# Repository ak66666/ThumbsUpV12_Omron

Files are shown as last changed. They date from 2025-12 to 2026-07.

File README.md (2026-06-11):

# ThumbsUp! v12 RP2040-based ProMicro 3x12 chord keyboard for Omron and mouse switches.
                           
Steno/chord keyboard (number key instead of a bar)
2-key Thumb Cluster
Cirque ProGlide trackpad/touchpad

Omron mouse switches or 6x6 two-pin switches.

* RP2040 ProMicro x2
* TRS (3-wire) audio cable to connect the halves.
* USB-C connectors.

Silicone O-rings are used for the key paddles suspension: CS2.4mm, OD 11mm (12mm works too).
Cross section 2-2.5 mm works well.
OD less than 11mm result in much heavier keys. 
OD more than 12mm is a bit too loose.

# Rev.5

Re-worked the cross-board connections: 
Replaced the mix of pin headers/sockets and stand-offs with individual stand-off for each key, plus one in a corner.
This way the boards should stay flat, no twisting due to minor height mismatch and the connectors pulled upwards unevenly.
Hopefully that will equalize the key reactions, uniform the feel.

Split the top board in two parts - to move the thumb keys higher and a bit closer to the index finger column. 
If it was left as a single detail - it would be C-shaped board with a thin profile, could be easily broken, and, probably, harder to manufacture and deliver.

Moved the MCU, connectors to make room for the stand-offs, re-laid the tracks where affected.

# Rev.4

Moved the keys as in rev.1, as the rev.3 inherited the spacing from rev.2 and was a bit uncomfortable.

# Rev.3

Approx. 15g activation with Omron switches, reduced from the previous revisions.
Cirque ProGlide trackpad support - on both or one of the sides.
Handiness pin added.

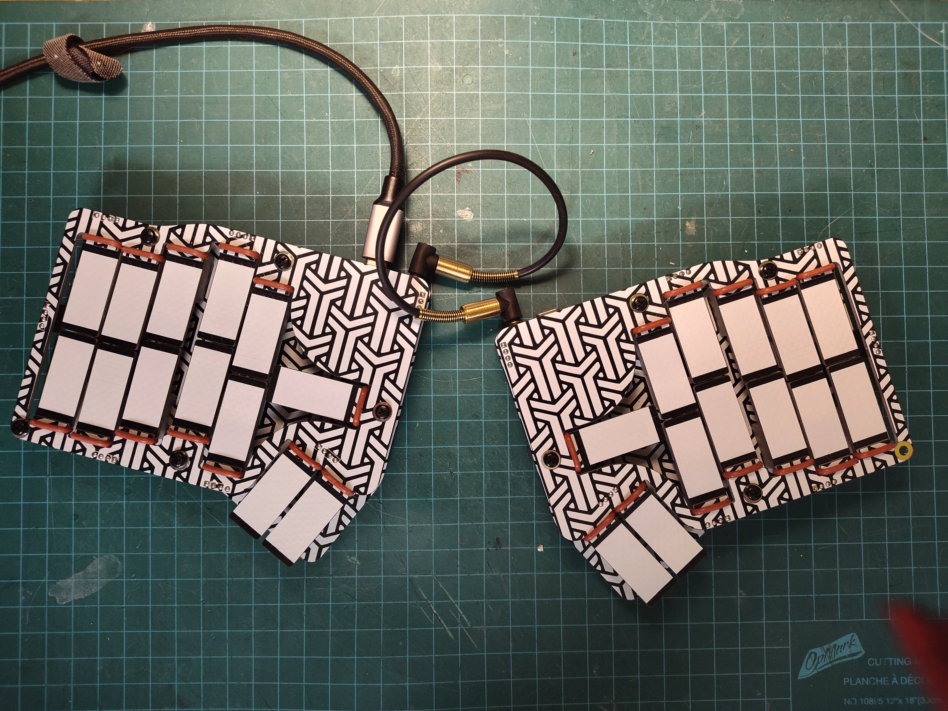
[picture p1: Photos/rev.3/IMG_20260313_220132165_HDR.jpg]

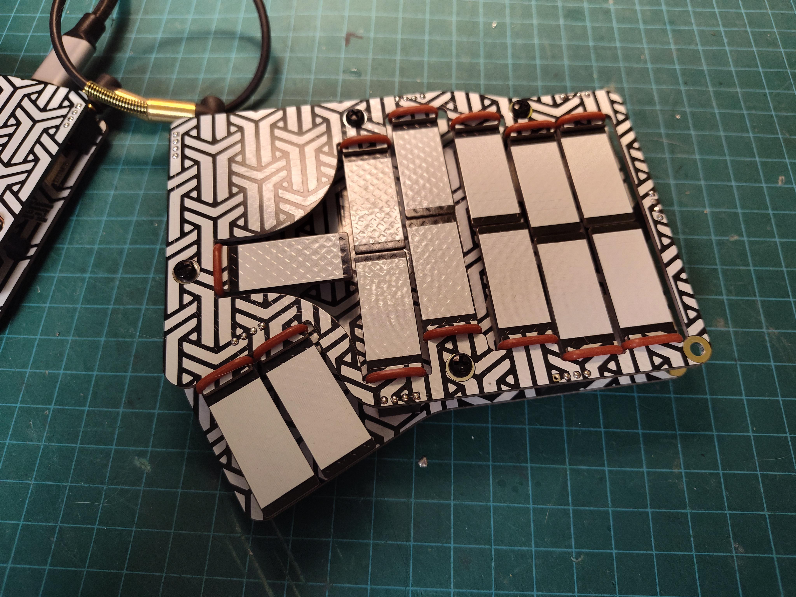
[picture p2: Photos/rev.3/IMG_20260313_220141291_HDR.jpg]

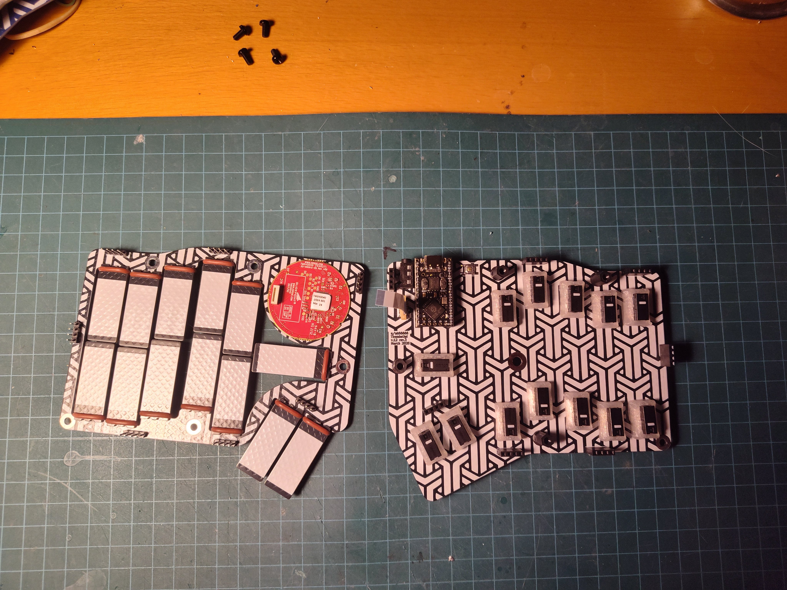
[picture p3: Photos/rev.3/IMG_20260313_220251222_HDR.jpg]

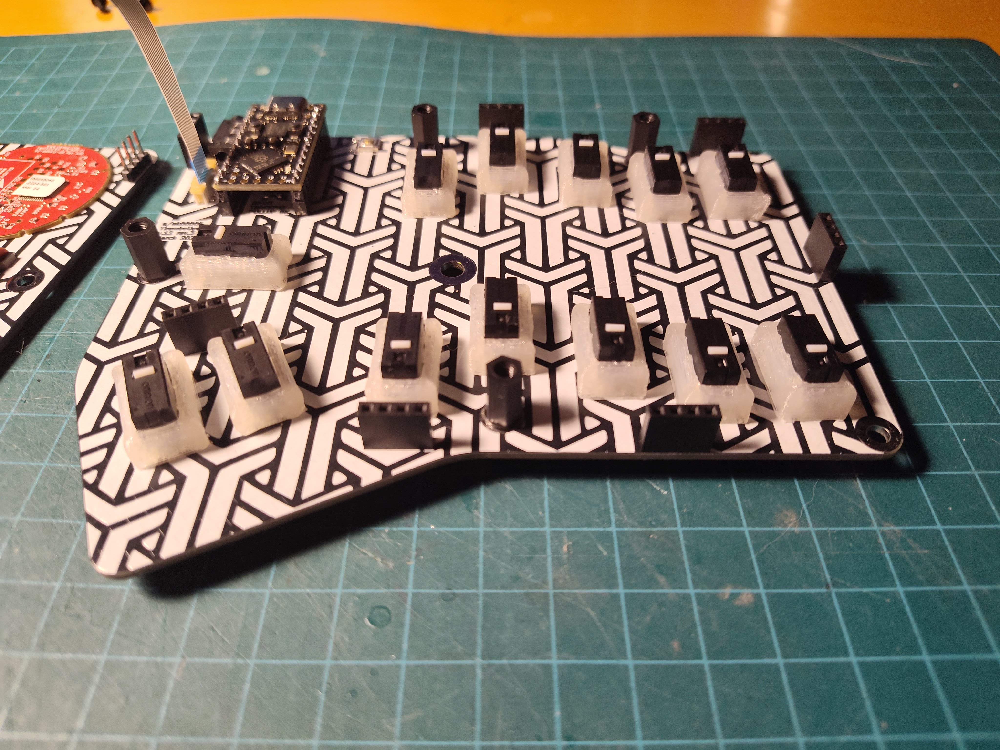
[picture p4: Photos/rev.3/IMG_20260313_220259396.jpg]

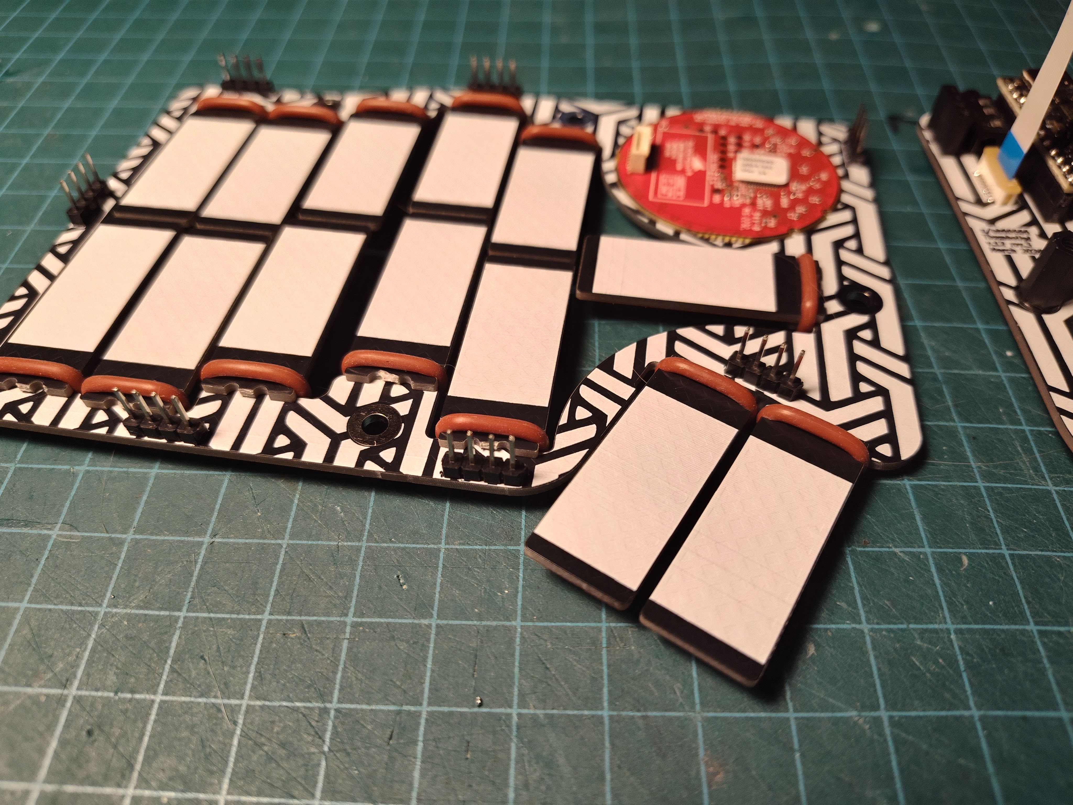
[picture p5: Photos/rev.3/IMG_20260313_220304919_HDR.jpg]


# Rev.2

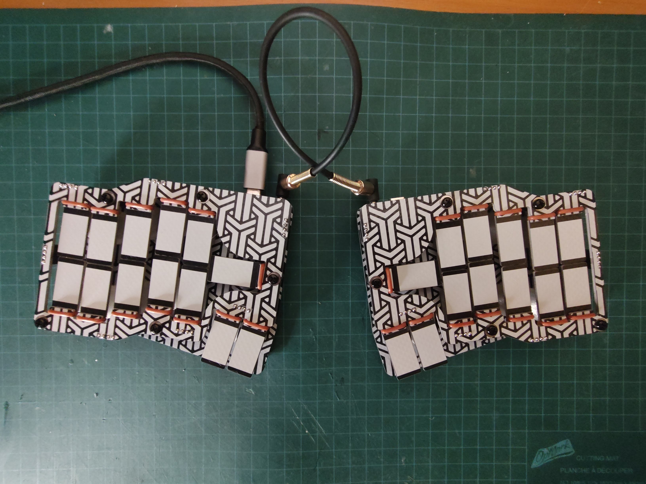
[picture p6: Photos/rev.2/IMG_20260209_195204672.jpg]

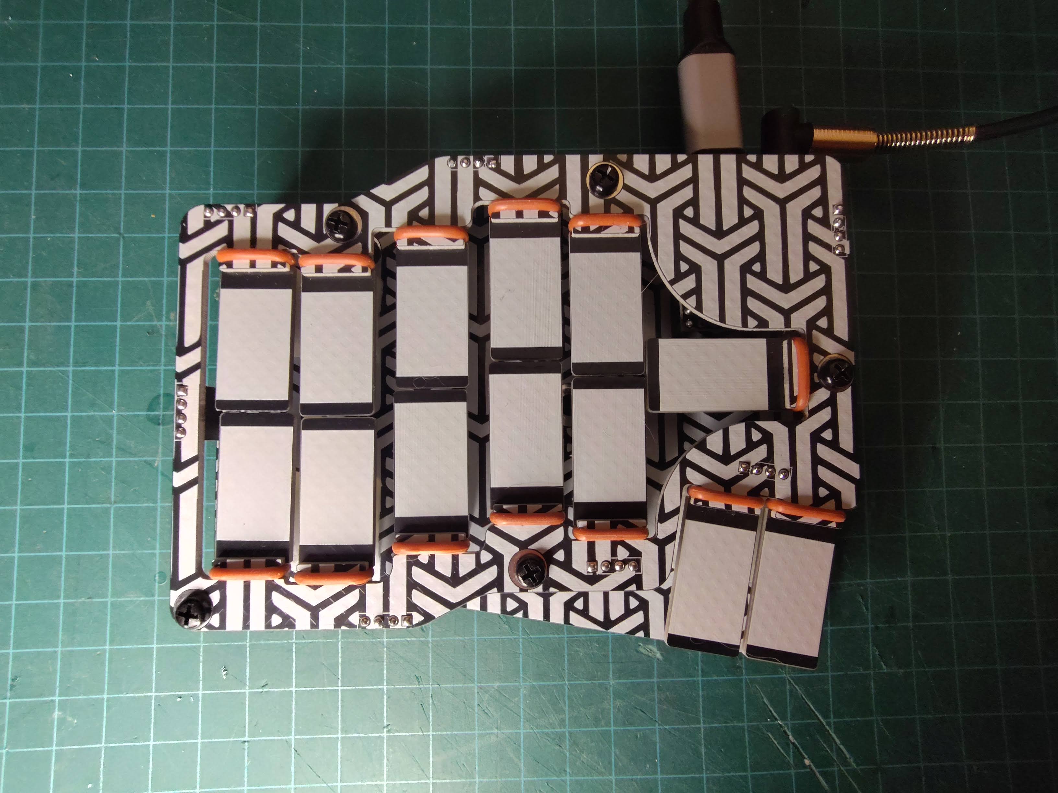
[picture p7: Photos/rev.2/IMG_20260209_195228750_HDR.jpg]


# Rev.1

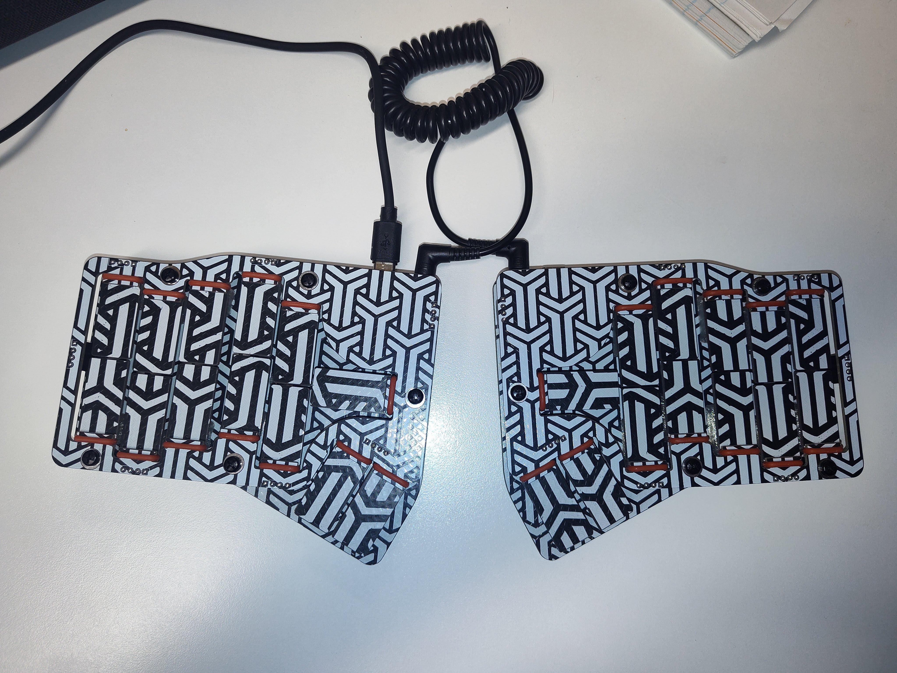
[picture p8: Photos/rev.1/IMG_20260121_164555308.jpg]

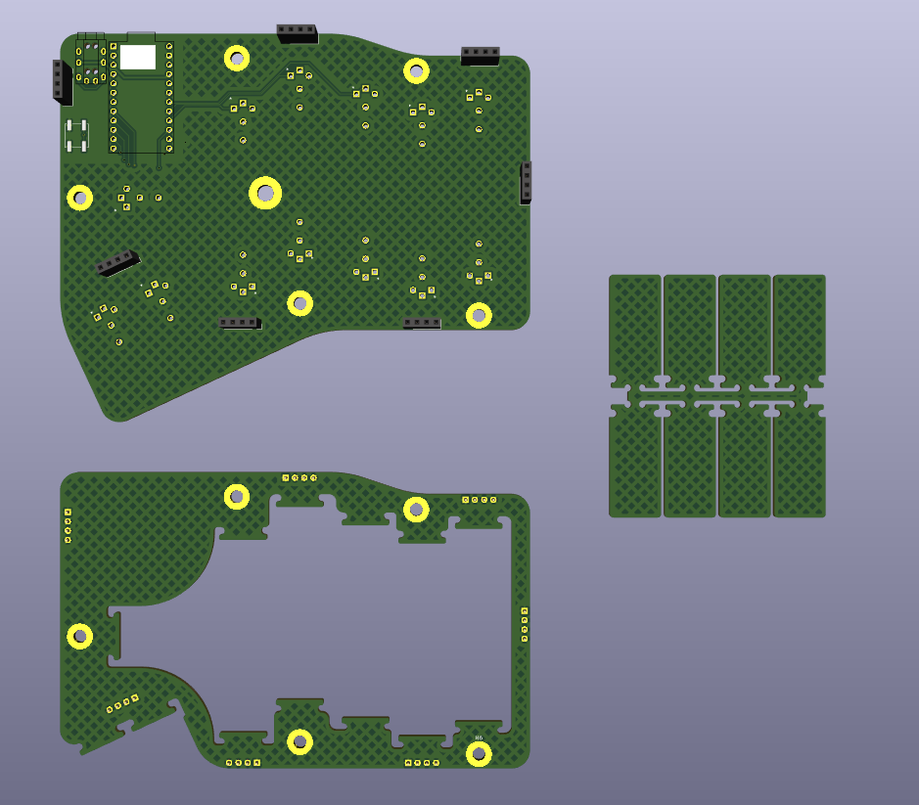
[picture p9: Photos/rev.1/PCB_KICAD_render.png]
PCB Render

 
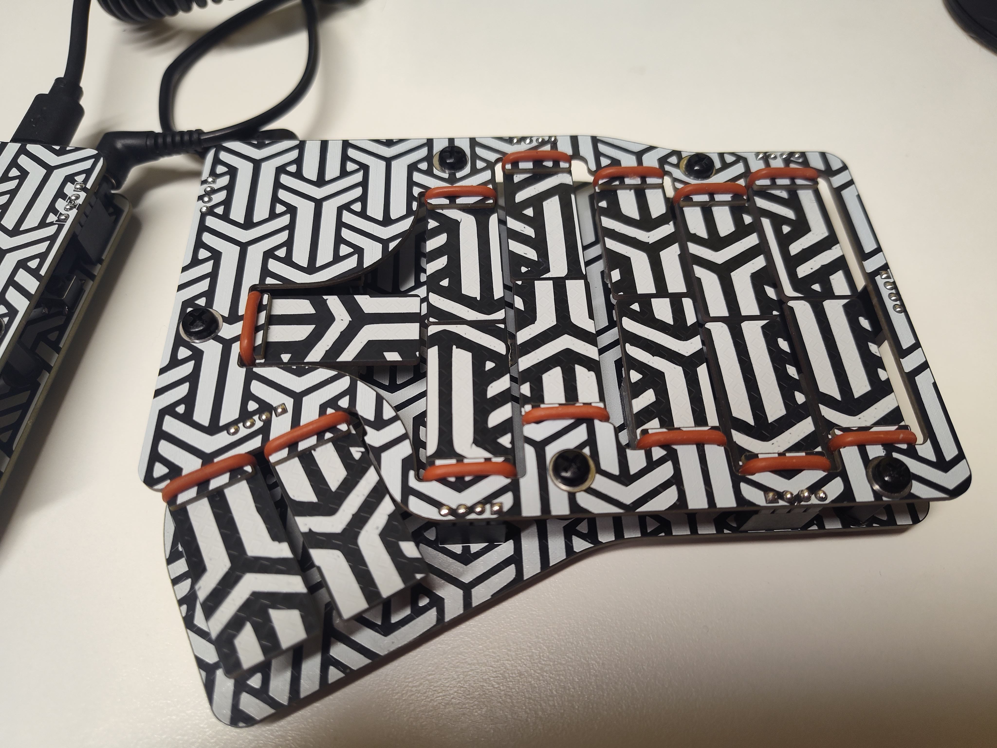
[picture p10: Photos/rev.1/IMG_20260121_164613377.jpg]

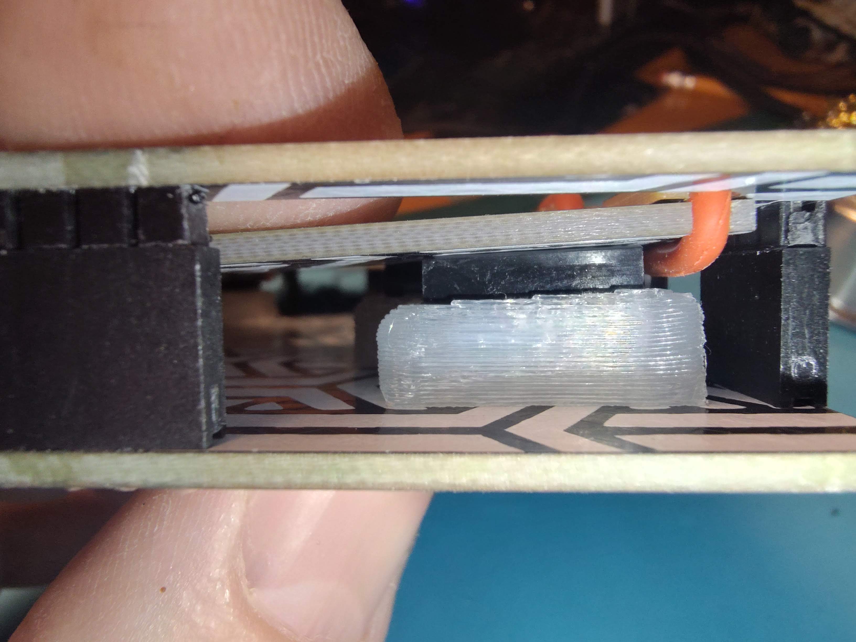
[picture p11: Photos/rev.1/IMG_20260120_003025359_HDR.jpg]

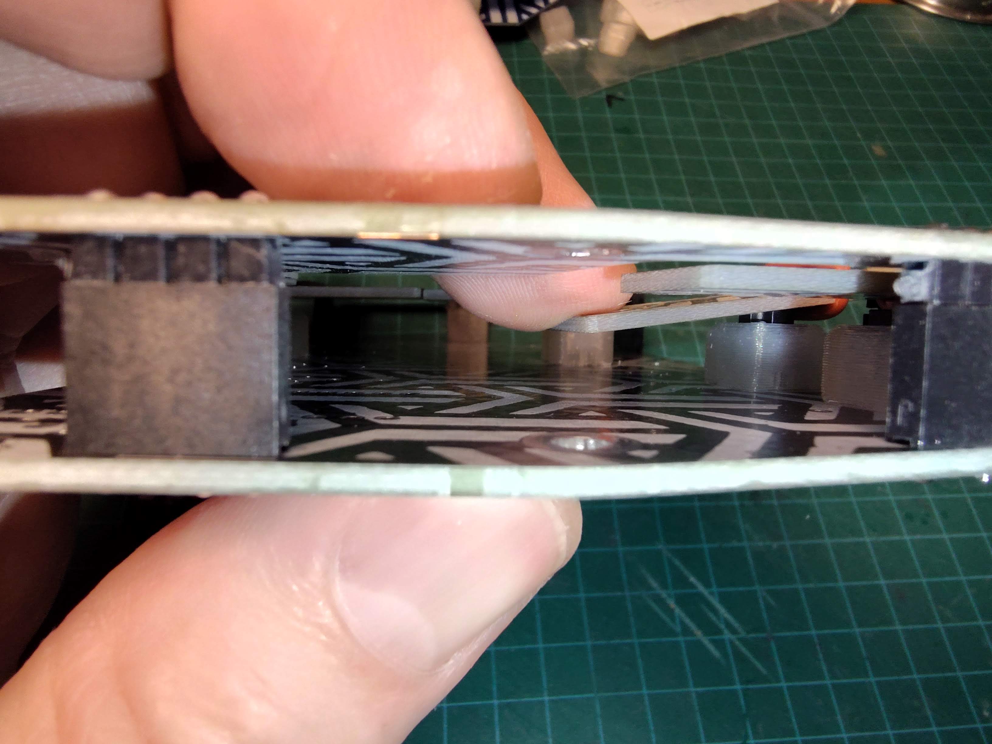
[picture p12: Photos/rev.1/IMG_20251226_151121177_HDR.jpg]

Main view

Other pictures and videos in Photos folder.

# Firmware

TX-Bolt interface as the only connectivity option for now:
https://github.com/ak66666/qmk_firmware/tree/thumbsup_20240523/keyboards/thumbsup/rev12_rp2040_split_steno

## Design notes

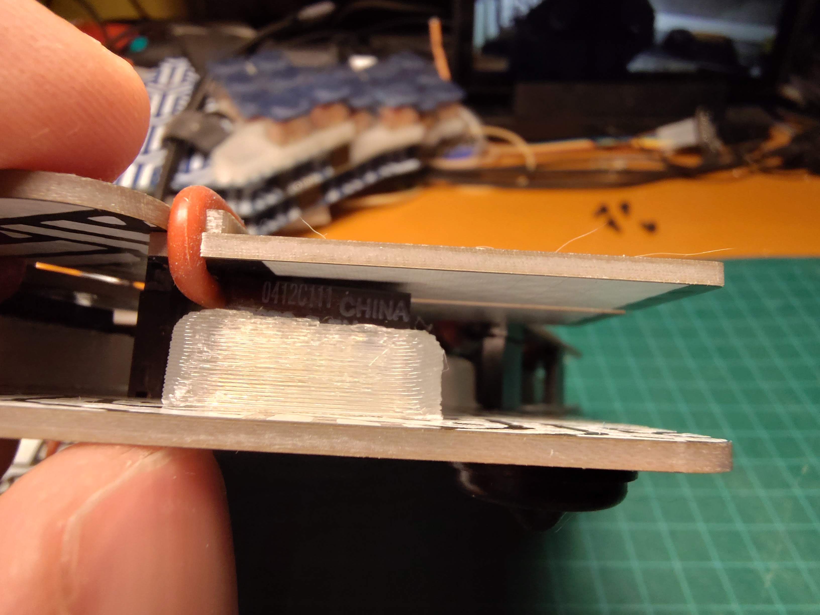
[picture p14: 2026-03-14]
Photos/rev.3/IMG_20260313_220356602_HDR.jpg

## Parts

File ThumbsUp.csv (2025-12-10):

Id | Designator | Package | Quantity | Designation | Supplier and ref
1 | RUN,BOOTSEL | TL1016AAF220QG | 2 | TL1016AAF220QG
2 | IC1 | QFN40P700X700X90-57N-D | 1 | RP2040
3 | D25,D44,D43,D42,D41,D40,D39,D38,D37,D36,D35,D34,D33,D32,D31,D30,D29,D28,D27,D26,D24,D23,D22,D21,D20,D19,D18,D17,D16,D15,D14,D13,D12,D11,D10,D9,D8,D7,D6,D5,D4,D3,D2,D1 | D_SOD-123 | 44 | D_Small
4 | Y1 | HC%2f49US-(AT49)_1 | 1 | ABLS-12.000MHZ-B4-T
5 | R3 | R_0805_2012Metric | 1 | 10k
6 | IC2 | SOIC127P790X216-8N | 1 | W25Q128JVSIM
7 | C9,C11 | C_0805_2012Metric | 2 | 10uF
8 | C7,C6,C2,C1,C17,C16,C15,C14,C13,C10 | C_0805_2012Metric | 10 | 0.1uF
9 | C5,C4 | C_0805_2012Metric | 2 | 27pF
10 | C3,C12 | C_0805_2012Metric | 2 | 1uF
11 | U1 | SOT-223-3_TabPin2 | 1 | NCP1117-3.3_SOT223
12 | R7 | R_0805_2012Metric | 1 | DNF
13 | R6 | R_0805_2012Metric | 1 | 1k
14 | R5,R4 | R_0805_2012Metric | 2 | 4.7k
15 | R2,R1 | R_0805_2012Metric | 2 | 27.4
16 | F1 | Fuse_1206_3216Metric | 1 | Polyfuse
17 | USB1 | Molex-0548190589 | 1 | Molex-0548190589
18 | J27,J24,J25,J26,J6,J4 | PinHeader_1x04_P2.54mm_Vertical | 6 | Conn_01x04_Male
19 | J18,J10,J14 | PinHeader_1x04_P2.54mm_Vertical | 3 | Raiser_Male
20 | MX38 | Kailh_socket_PG1350_optional | 1 | SwMENU
21 | MX27 | Kailh_socket_PG1350_optional | 1 | SwU
22 | MX28 | Kailh_socket_PG1350_optional | 1 | SwJ
23 | MX29 | Kailh_socket_PG1350_optional | 1 | SwM
24 | MX34 | Kailh_socket_PG1350_optional | 1 | SwRALT
25 | J20,J21,J22,J23 | PinSocket_1x04_P2.54mm_Vertical | 4 | Conn_01x04_Female
26 | MX15 | Kailh_socket_PG1350_optional | 1 | SwR
27 | MX24 | Kailh_socket_PG1350_optional | 1 | SwH
28 | MX10 | Kailh_socket_PG1350_optional | 1 | SwLWIN
29 | MX14 | Kailh_socket_PG1350_optional | 1 | SwLALT
30 | MX17 | Kailh_socket_PG1350_optional | 1 | SwV
31 | MX25 | Kailh_socket_PG1350_optional | 1 | SwN
32 | MX19 | Kailh_socket_PG1350_optional | 1 | SwT
33 | MX21 | Kailh_socket_PG1350_optional | 1 | SwB
34 | MX20 | Kailh_socket_PG1350_optional | 1 | SwG
35 | MX23 | Kailh_socket_PG1350_optional | 1 | SwY
36 | MX16 | Kailh_socket_PG1350_optional | 1 | SwF
37 | J15,J11 | PinSocket_1x04_P2.54mm_Vertical | 2 | Raiser_Female

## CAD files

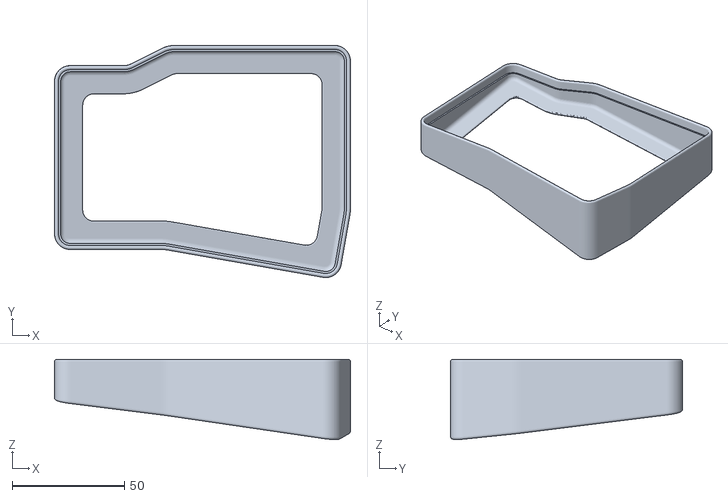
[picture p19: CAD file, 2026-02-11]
3D Printed/Base.stl
132.0 x 103.5 x 35.7

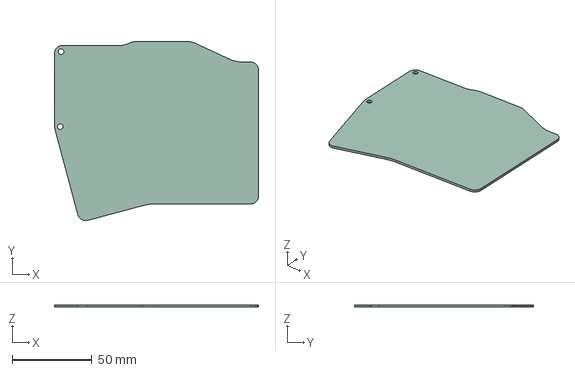
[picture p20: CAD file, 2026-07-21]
3D Printed/Rev.5/Bottom Plate rev.5.step
128.0 x 112.6 x 1.51 mm

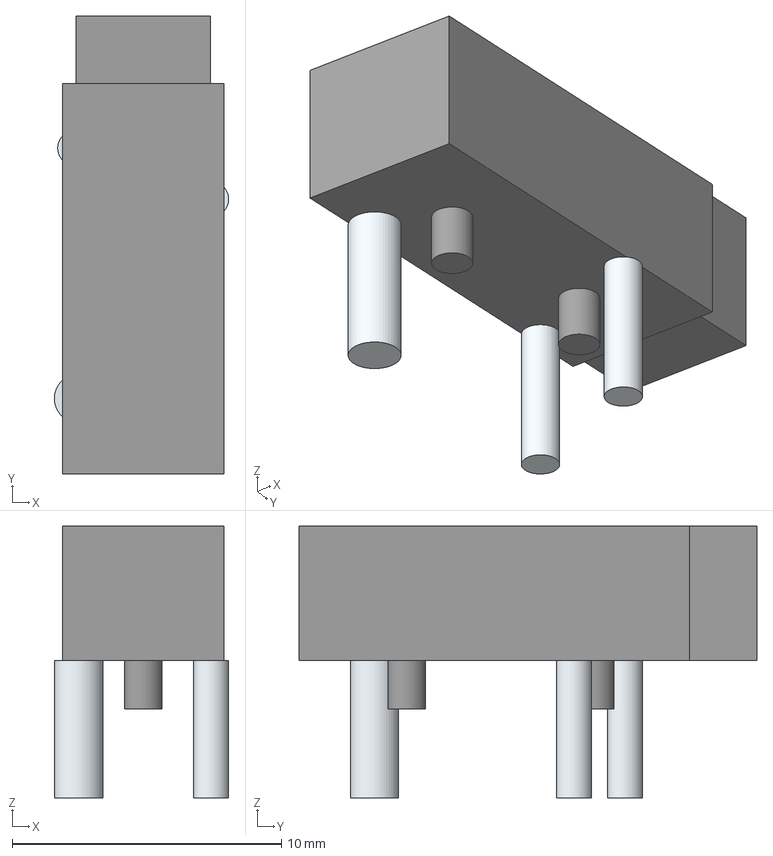
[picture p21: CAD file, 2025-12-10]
STX-3501-3N/3D/STX-3501-3N.stp
6.47 x 17.0 x 10.1 mm
Lugs
Leads

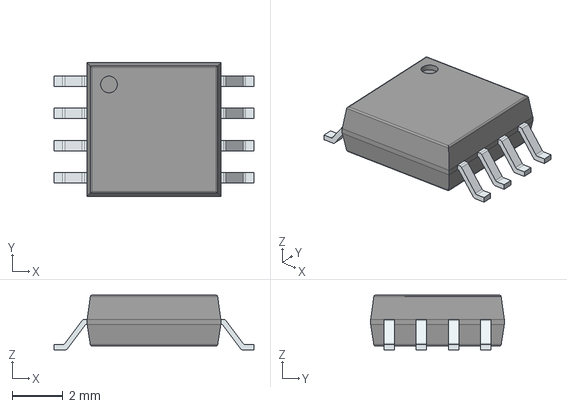
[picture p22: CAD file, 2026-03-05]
W25Q128JVSIM/3D/W25Q128JVSIM.stp
7.90 x 5.28 x 2.16 mm
PinsArrayLR

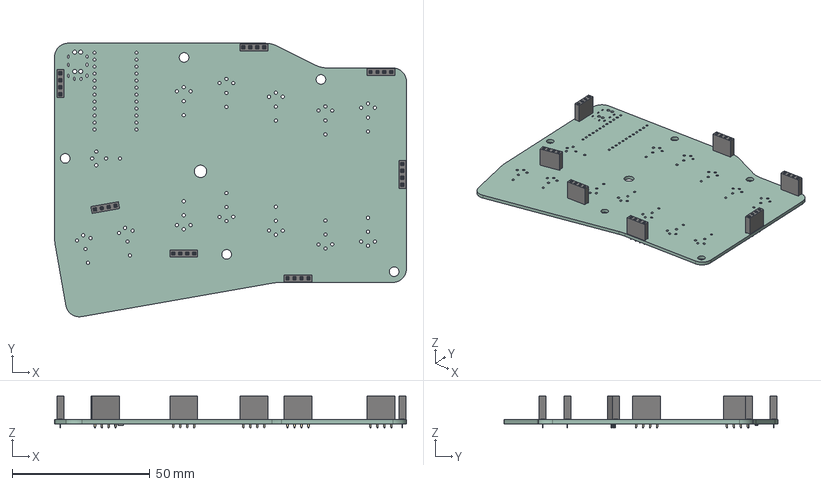
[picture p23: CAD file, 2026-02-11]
3D Printed/Bottom Plate.step
128.0 x 99.5 x 11.6 mm
PinSocket_1x04_P2.54mm_Vertical x 7
R_0805_2012Metric
ThumbsUp_PCB

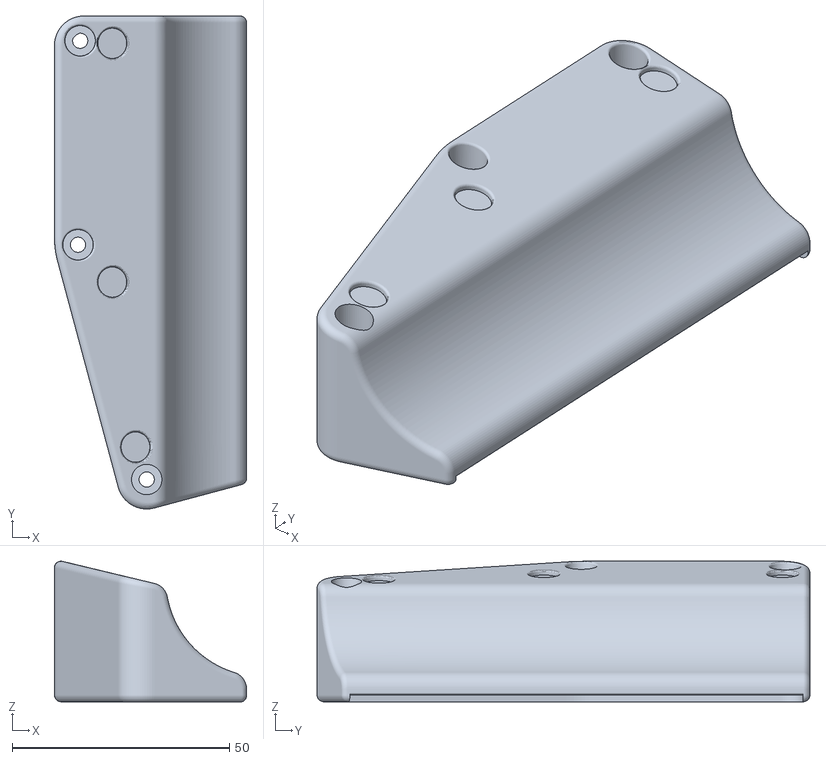
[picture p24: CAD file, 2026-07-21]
3D Printed/Rev.5/v12 rev5 Heel Left.stl
44.3 x 113.6 x 32.4

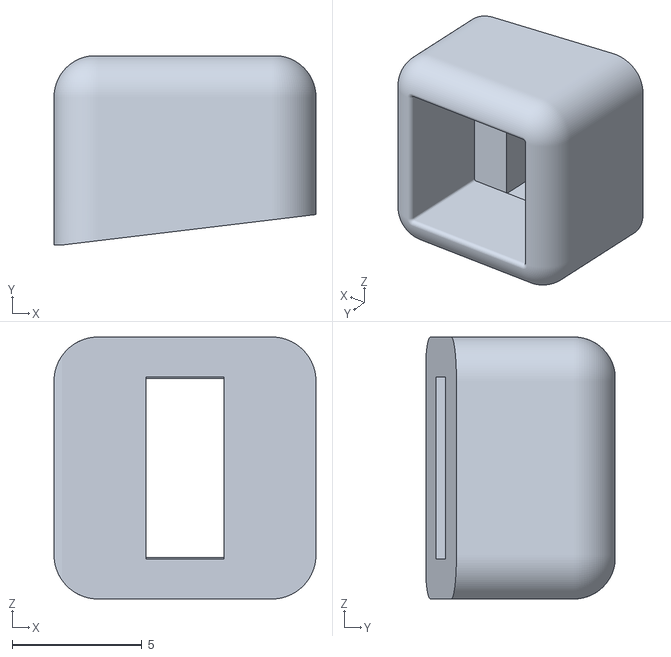
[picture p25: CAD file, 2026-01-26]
3D Printed/Switch Raiser 6x6 Tilted.stl
10.1 x 7.29 x 10.1

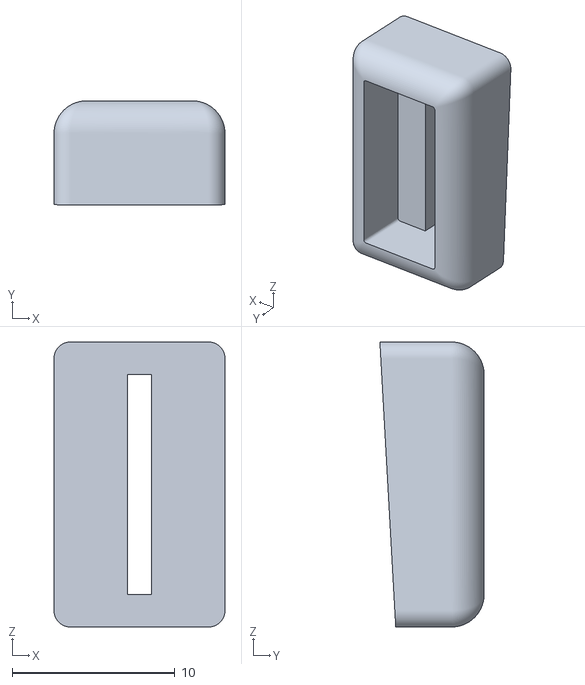
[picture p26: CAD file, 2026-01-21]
3D Printed/Switch Raiser Omron Tilted.stl
10.5 x 6.40 x 17.5

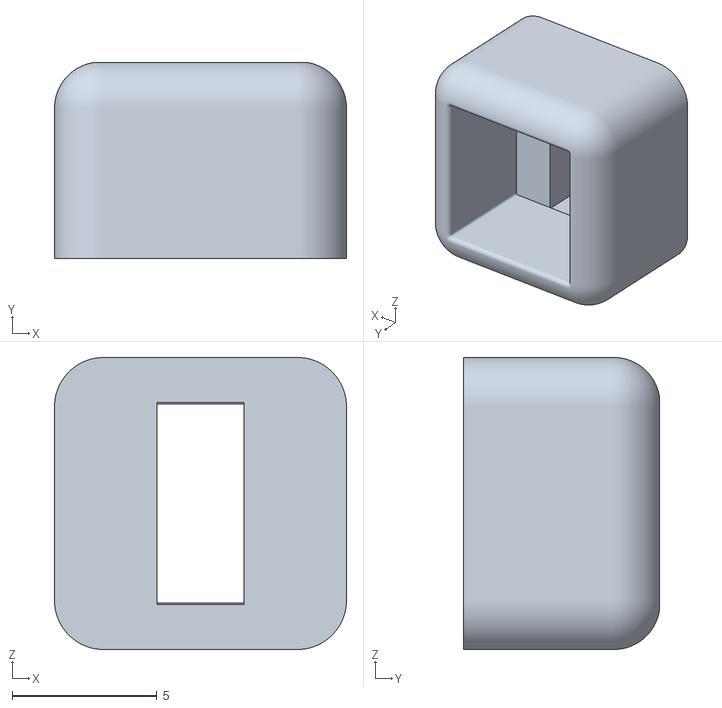
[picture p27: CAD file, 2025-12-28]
3D Printed/Switch Raiser 6x6.stl
10.1 x 6.79 x 10.1

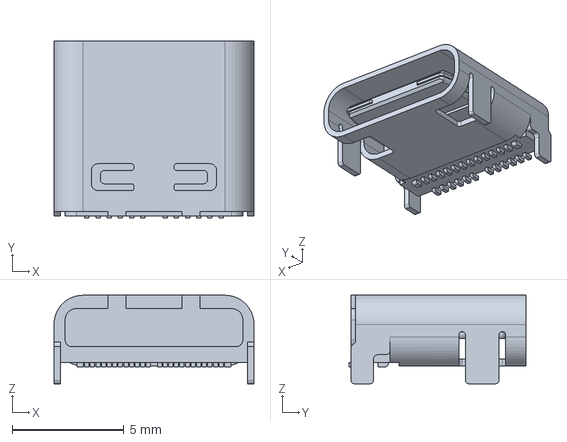
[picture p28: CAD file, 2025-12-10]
105450-0101/3D/105450-0101.stp
8.94 x 7.90 x 3.96 mm

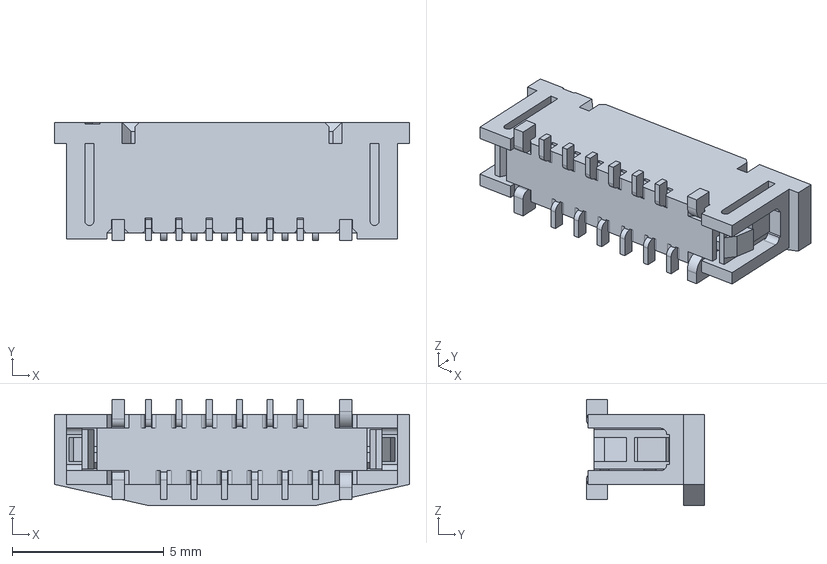
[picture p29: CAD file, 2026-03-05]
Molex 52559-1233/52559-1233/3D/52559-1233.stp
11.7 x 3.90 x 3.50 mm

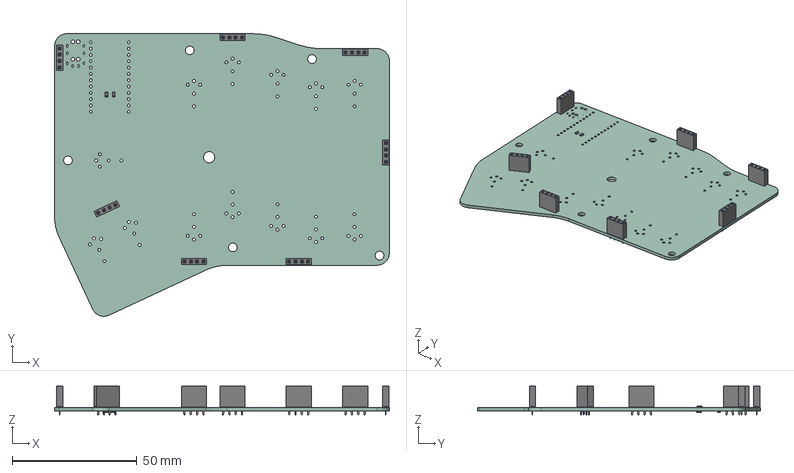
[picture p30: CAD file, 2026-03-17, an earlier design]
3D Printed/Rev.3/Bottom Plate rev.3.step
134.5 x 113.5 x 11.6 mm
PinSocket_1x04_P2.54mm_Vertical x 7
R_0805_2012Metric x 5
ThumbsUp_PCB

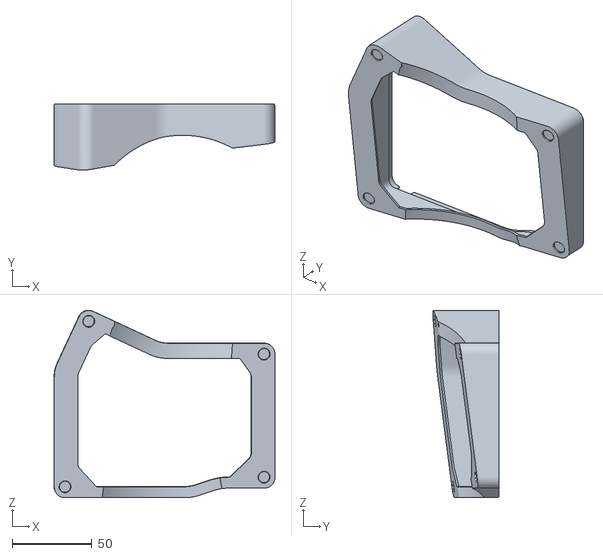
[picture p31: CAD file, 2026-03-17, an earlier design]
3D Printed/Rev.3/Hip Base rev.3.stl
138.2 x 41.6 x 117.2

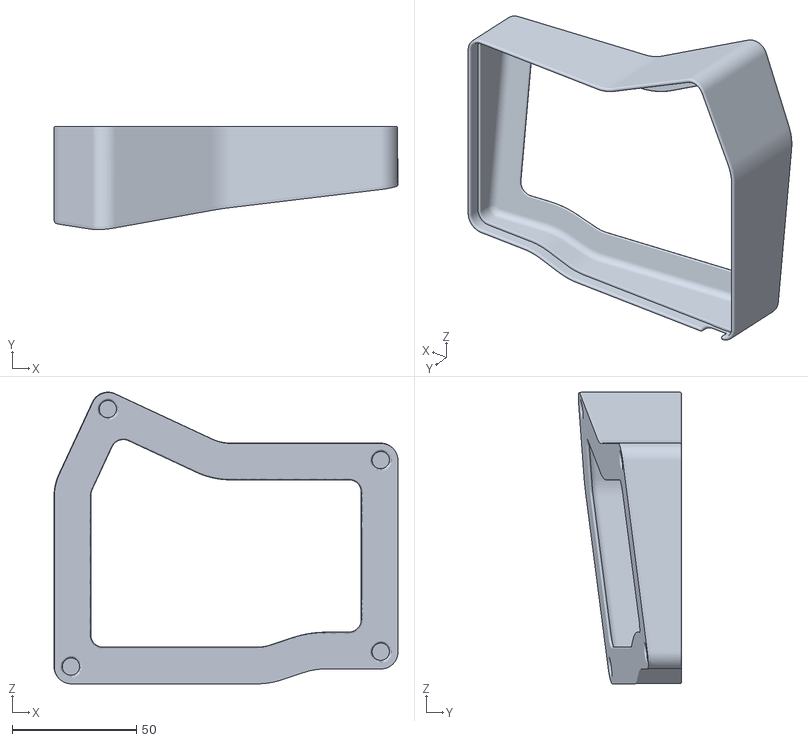
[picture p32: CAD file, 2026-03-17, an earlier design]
3D Printed/Rev.3/Base rev.3.stl
138.2 x 41.6 x 117.2

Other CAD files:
EVQ-P7B01P/Allegro/evqp7b01p.psm
EVQ-P7B01P/DEHDL/evq_p7b01p/chips/chips.prt
Molex 52559-1233/52559-1233/Allegro/525591233.psm
Molex 52559-1233/52559-1233/DEHDL/52559_1233/chips/chips.prt
STX-3501-3N/Allegro/stx35013n.psm
STX-3501-3N/DEHDL/stx_3501_3n/chips/chips.prt
TL1016AAF220QG/Allegro/tl1016aaf220qg.psm
TL1016AAF220QG/DEHDL/tl1016aaf220qg/chips/chips.prt
W25Q128JVSIM/Allegro/soic127p790x216-8n.psm
W25Q128JVSIM/DEHDL/w25q128jvsim/chips/chips.prt

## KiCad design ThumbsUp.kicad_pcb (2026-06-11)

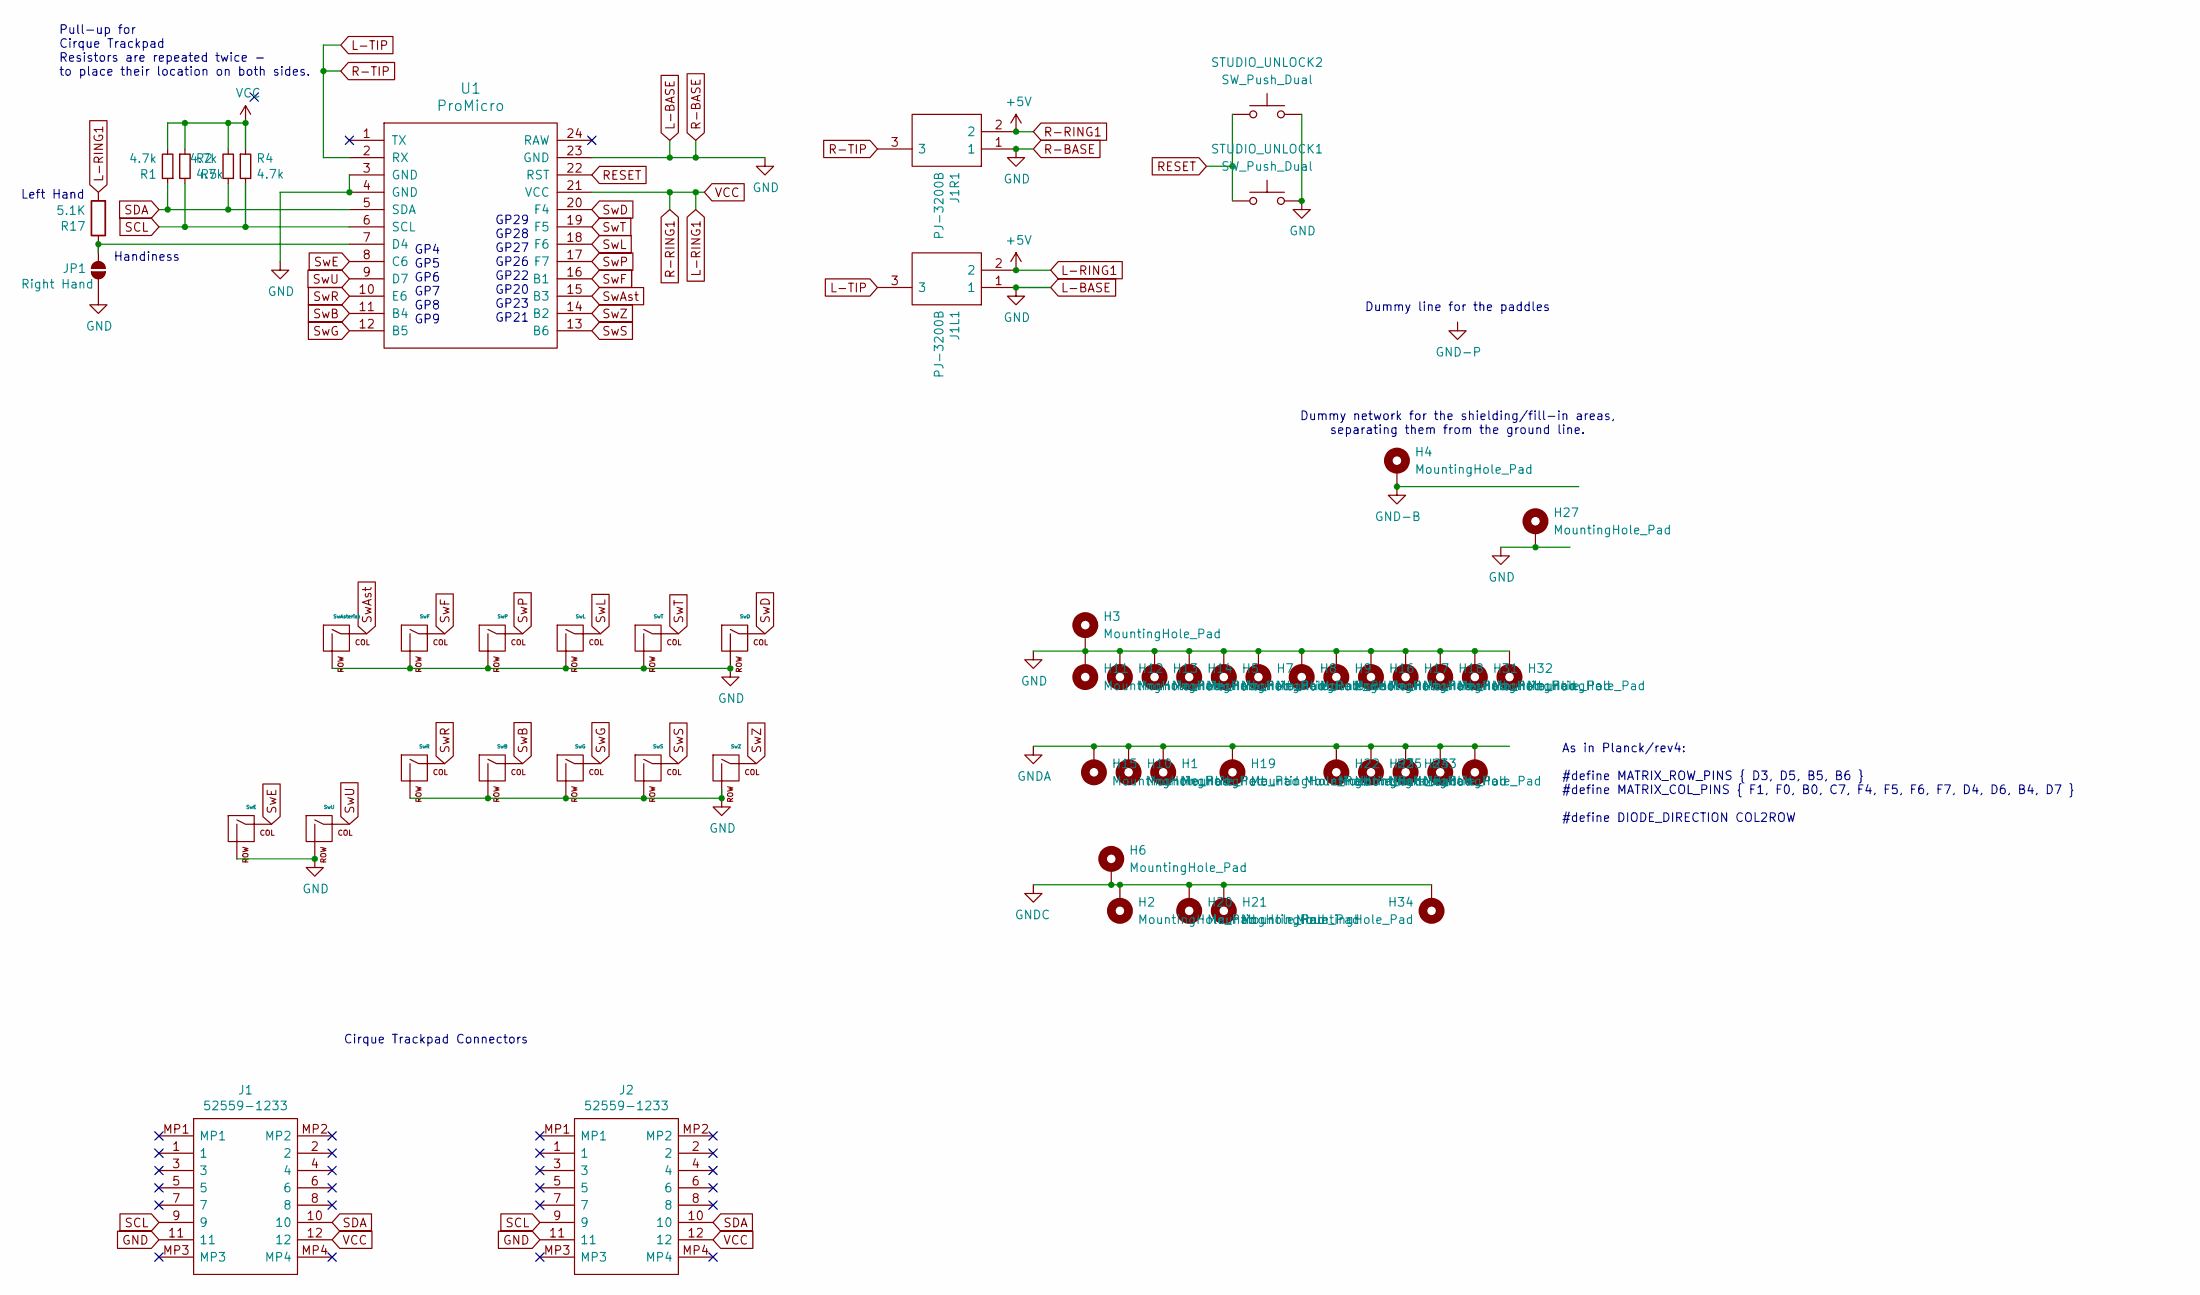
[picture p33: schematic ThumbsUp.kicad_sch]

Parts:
H1, H2, H3, H5, H6, H7, H8, H9, H10, H11, H12, H13, H14, H15, H16, H17, H18, H19, H20, H21, H22, H23, H24, H25, H27, H31, H32, H33, H34: MountingHole_Pad; MountingHole_3.5mm_Pad
H4: MountingHole_Pad; MountingHole_4.5mm_Pad
J1, J2: 52559-1233; 525591233; Mouser Part Number 538-52559-1233
J1L1, J1R1: PJ-3200B; PJ-3200B-4A; Manufacturer_Part_Number STX-3501-3N; Mouser Part Number 806-STX-3501-3N
JP1: Right Hand; SolderJumper-2_P1.3mm_Open_RoundedPad1.0x1.5mm
MX23: SwAsterisk; SW_D2FC_OMR
MX26: SwU; SW_D2FC_OMR
MX27: SwF; SW_D2FC_OMR
MX28: SwR; SW_D2FC_OMR
MX30: SwE; SW_D2FC_OMR
MX31: SwP; SW_D2FC_OMR
MX32: SwB; SW_D2FC_OMR
MX35: SwL; SW_D2FC_OMR
MX36: SwG; SW_D2FC_OMR
MX39: SwT; SW_D2FC_OMR
MX40: SwS; SW_D2FC_OMR
MX42: SwD; SW_D2FC_OMR
MX43: SwZ; SW_D2FC_OMR
R1, R2, R4, R5: 4.7k; R_0805_2012Metric
R17: 5.1K; R_0805_2012Metric
STUDIO_UNLOCK1, STUDIO_UNLOCK2: SW_Push_Dual; SW_Push_1P1T_NO_CK_KSC6xxJ
U1: ProMicro; ProMicro-NoSilk

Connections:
GND: H3.1, H5.1, H7.1, H8.1, H9.1, H11.1, H12.1, H13.1, H14.1, H16.1, H17.1, H18.1, H27.1, H31.1, H32.1, J1.11, J1L1.1, J1R1.1, J2.11, JP1.1 (A), MX23.2 (ROW), MX26.2 (ROW), MX27.2 (ROW), MX28.2 (ROW), MX30.2 (ROW), MX31.2 (ROW), MX32.2 (ROW), MX35.2 (ROW), MX36.2 (ROW), MX39.2 (ROW), MX40.2 (ROW), MX42.2 (ROW), MX43.2 (ROW), STUDIO_UNLOCK1.2, STUDIO_UNLOCK2.2, U1.3 (GND), U1.4 (GND), U1.23 (GND)
GND-B: H4.1
GNDA: H1.1, H10.1, H15.1, H19.1, H22.1, H23.1, H24.1, H25.1, H33.1
GNDC: H2.1, H6.1, H20.1, H21.1, H34.1
L-RING1: J1.12, J1L1.2, J1R1.2, J2.12, R1.2, R2.1, R4.1, R5.2, R17.2, U1.21 (VCC)
L-TIP: J1L1.3, J1R1.3, U1.2 (RX)
unnamed: JP1.2 (B), R17.1, U1.7 (D4)
RESET: STUDIO_UNLOCK1.1, STUDIO_UNLOCK2.1, U1.22 (RST)
SCL: J1.9, J2.9, R2.2, R4.2, U1.6 (SCL)
SDA: J1.10, J2.10, R1.1, R5.1, U1.5 (SDA)
SwAst: MX23.1 (COL), U1.15 (B3)
SwB: MX32.1 (COL), U1.11 (B4)
SwD: MX42.1 (COL), U1.20 (F4)
SwE: MX30.1 (COL), U1.8 (C6)
SwF: MX27.1 (COL), U1.16 (B1)
SwG: MX36.1 (COL), U1.12 (B5)
SwL: MX35.1 (COL), U1.18 (F6)
SwP: MX31.1 (COL), U1.17 (F7)
SwR: MX28.1 (COL), U1.10 (E6)
SwS: MX40.1 (COL), U1.13 (B6)
SwT: MX39.1 (COL), U1.19 (F5)
SwU: MX26.1 (COL), U1.9 (D7)
SwZ: MX43.1 (COL), U1.14 (B2)

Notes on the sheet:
Pull-up for Cirque Trackpad Resistors are repeated twice - to place their location on both sides.
As in Planck/rev4: #define MATRIX_ROW_PINS { D3, D5, B5, B6 } #define MATRIX_COL_PINS { F1, F0, B0, C7, F4, F5, F6, F7, D4, D6, B4, D7 } #define DIODE_DIRECTION COL2ROW
Cirque Trackpad Connectors
GP4 GP5 GP6 GP7 GP8 GP9
GP29 GP28 GP27 GP26 GP22 GP20 GP23 GP21
Left Hand
Dummy line for the paddles
Handiness
Dummy network for the shielding/fill-in areas, separating them from the ground line.

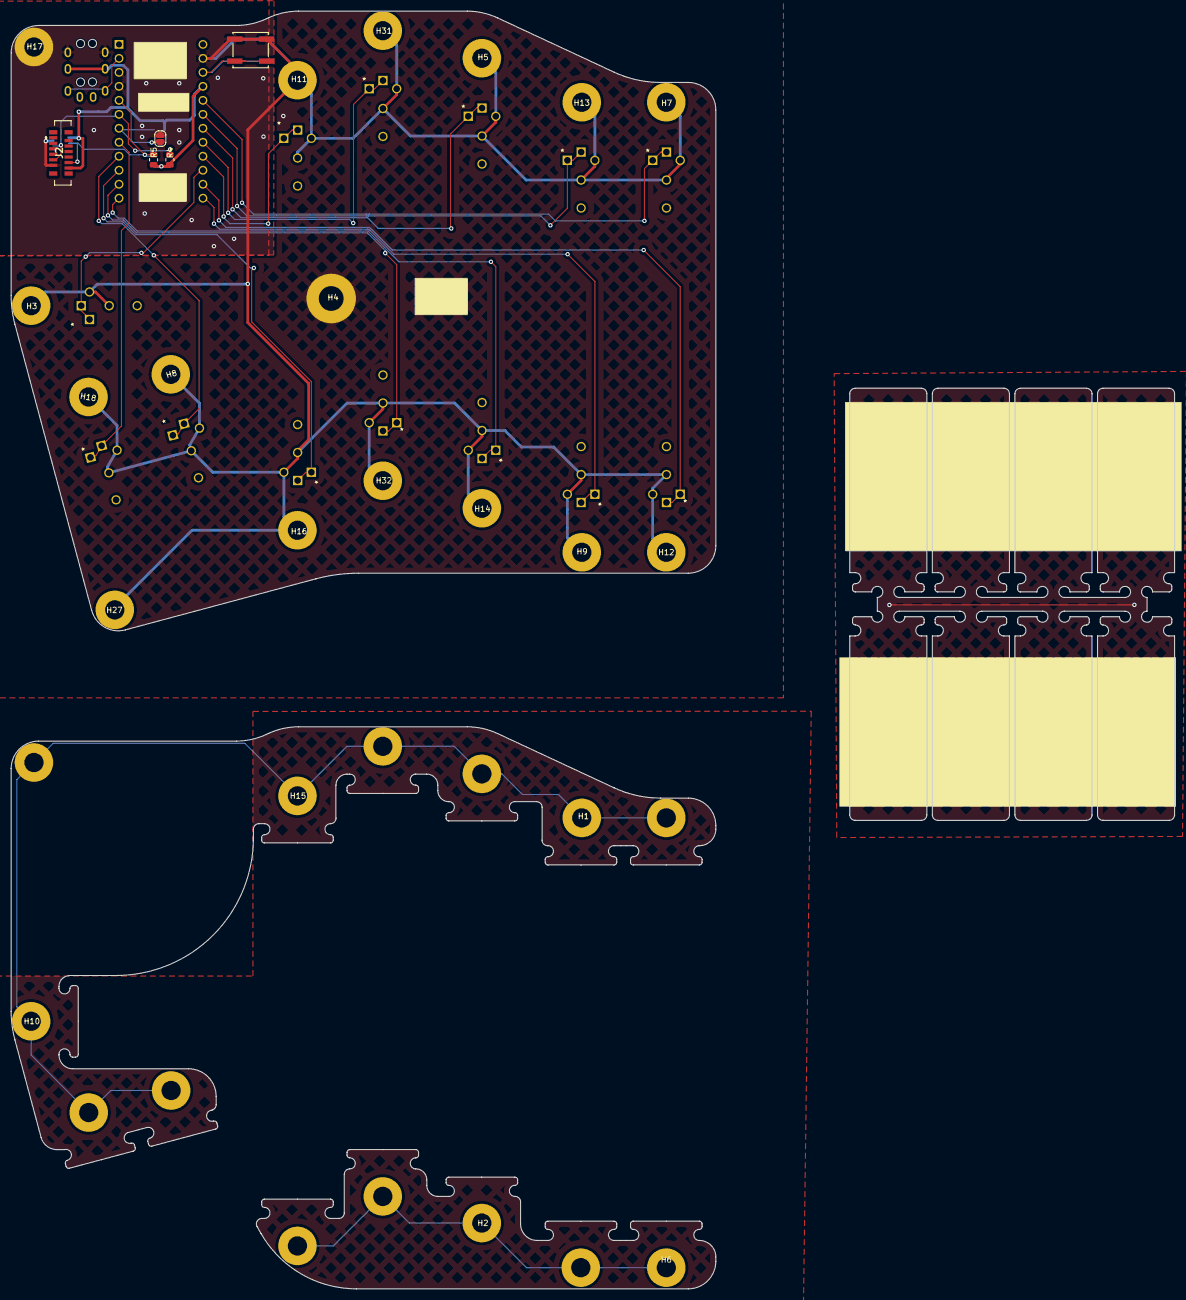
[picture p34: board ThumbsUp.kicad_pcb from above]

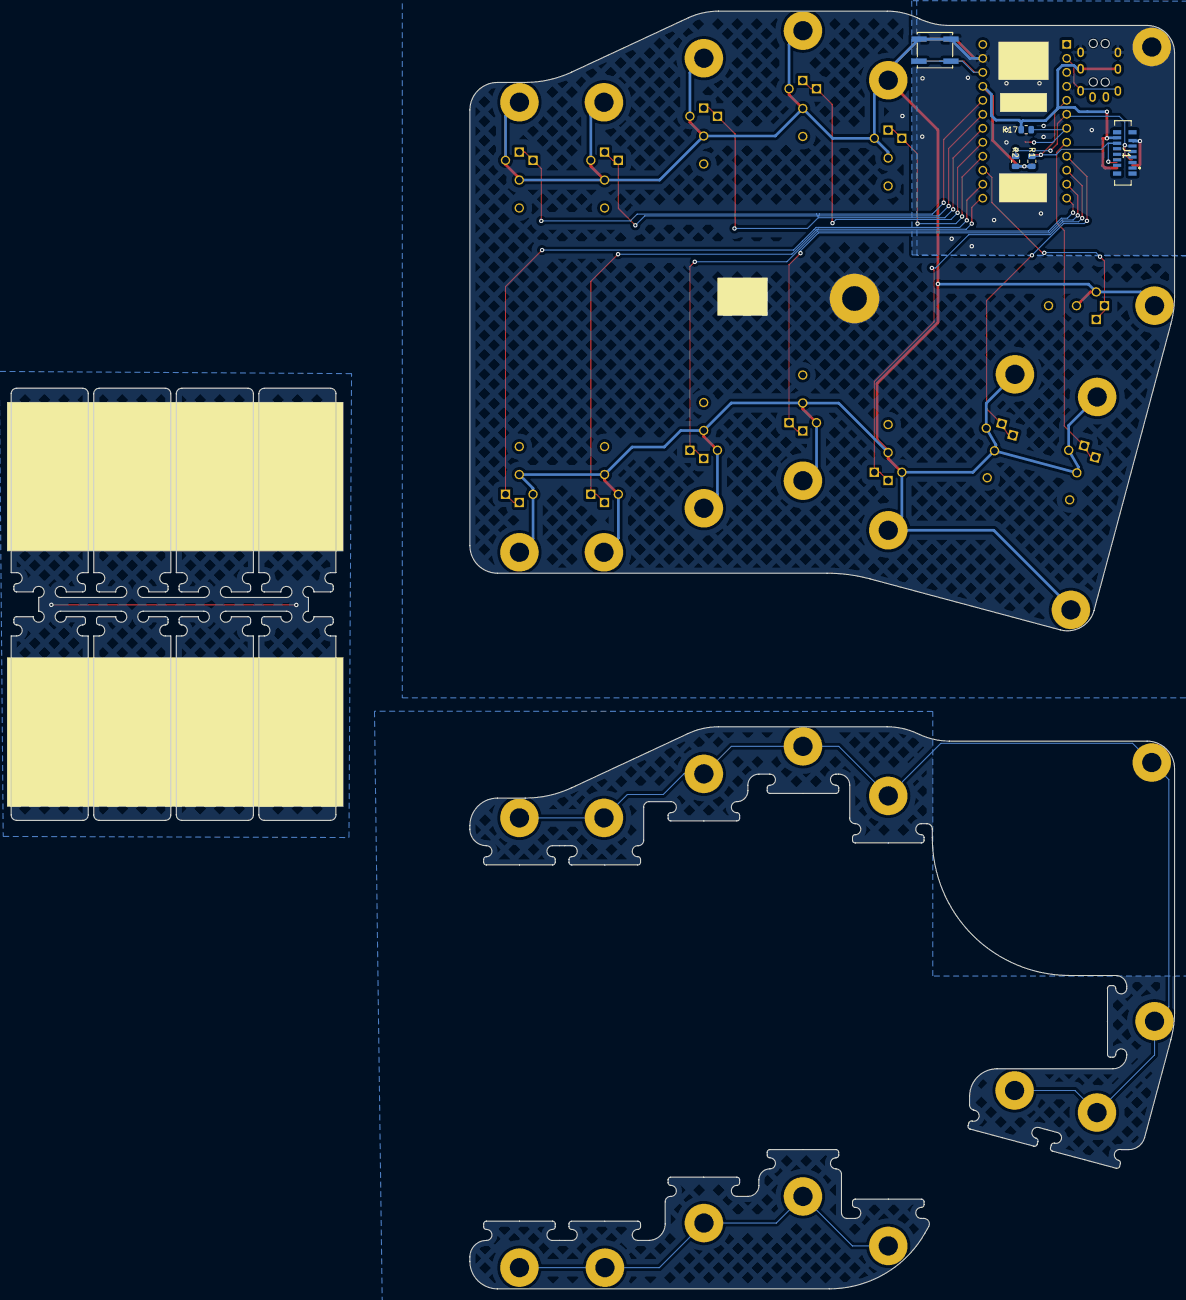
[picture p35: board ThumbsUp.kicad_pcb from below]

Board: 2 copper layers, 211.3 x 232.1 mm, 56 parts (6 on the bottom side), 22 nets.

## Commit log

2025-12-10 K12: First outline
    [105450-0101.stp, EDI2CAP.CFG, STX-3501-3N.SchLib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]
2025-12-10 K12: Draft schematics, initial physical layout.
    [ThumbsUp.kicad_pcb, ThumbsUp.kicad_sch]
2025-12-11 K12: Before splitting the boards.
    [ThumbsUp.kicad_pcb, ThumbsUp.kicad_sch]
2025-12-11 K12: Before generating Kerbers.
    [ThumbsUp.kicad_sch]
2025-12-11 K12: As ordered 2025-12-10
    [ThumbsUp-B_Cu.gbr, ThumbsUp-B_Mask.gbr, ThumbsUp-B_Paste.gbr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]
2025-12-11 K12: Added a mounting hole. Moved the tracks a bit. Haven't modified the gerbers
    [ThumbsUp.kicad_sch]
2025-12-28 K12: Modifying the layout, WIP.
    [Switch Raiser 6x6.stl, ThumbsUp.kicad_pcb, ThumbsUp.kicad_sch]
2026-01-02 K12: Regenerated gerbers, as ordered 20260101.
    [ThumbsUp-B_Cu.gbr, ThumbsUp-B_Mask.gbr, ThumbsUp-B_Paste.gbr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]
2026-01-21 K12: rev.1 with pictures.
    [Switch Raiser Omron Tilted.stl]
2026-01-26 K12: New switch supports - tilted.
    [Switch Raiser 6x6 Tilted.stl]
2026-01-27 K12: Changed layout as per rev.1 usage experience.
    [ThumbsUp.kicad_pcb]
2026-01-27 K12: Added left-side handiness pull-up R, laid out all tracks. TODO: generate Gerbers.
    [ThumbsUp.kicad_pcb, ThumbsUp.kicad_sch]
2026-01-28 K12: Gerbers generated. As ordered 20260127.
    [ThumbsUp-B_Cu.gbr, ThumbsUp-B_Mask.gbr, ThumbsUp-B_Paste.gbr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]
2026-02-10 K12: Added photos of rev.1 with Omron switches.
2026-02-11 K12: Added a tilted/tented base.
    [Base.stl, Bottom Plate.step]
2026-03-05 K12: Doing modifications outlined for rev.3
    [ThumbsUp.kicad_pcb, ThumbsUp.kicad_sch]
2026-03-05 K12: Placed the touchpad, todo: tracks
    [52559-1233.stp, 525591233.psm, EDI2CAP.CFG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]
2026-03-06 K12: Placed the tracks, text, etc. TODO: generate Gerbers.
    [ThumbsUp.kicad_pcb, ThumbsUp.kicad_sch]
2026-03-07 K12: Moved the thumb keys a bit up, closer to the fingers. TODO: generate Gerbers.
    [ThumbsUp-B_Cu.gbr, ThumbsUp-B_Mask.gbr, ThumbsUp-B_Paste.gbr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]
2026-03-07 K12: Added Gerbers as ordered 20260306.
    [ThumbsUp-B_Cu.gbr, ThumbsUp-B_Mask.gbr, ThumbsUp-B_Paste.gbr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]
2026-03-14 K12: Added pictures of rev.3.
    [ThumbsUp.kicad_sch]
2026-03-17 K12: Moved the pinkie cluster 4mm out, 3mm down.//TODO: generate Gerbers
    [Base rev.3.stl, Bottom Plate rev.3.step, Hip Base rev.3.stl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]
2026-03-17 K12: Moved the top border a bit to thicken the bridge between -L and -T. Shuffled the stand-offs and headers around to space them more evenly.//TODO: generate Gerbers
    [ThumbsUp.kicad_pcb]
2026-03-17 K12: Recreated Gerbers. As Ordered 20260317.
    [ThumbsUp-B_Cu.gbr, ThumbsUp-B_Mask.gbr, ThumbsUp-B_Paste.gbr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]
2026-06-02 v12: Replaced pin headers/sockets with stand-offs..
    [ThumbsUp.kicad_pcb, ThumbsUp.kicad_sch]
2026-06-10 v12: Moving the thumb keys around.
    [ThumbsUp.kicad_pcb, ThumbsUp.kicad_sch]
2026-06-11 v12: Added stand-offs instead of pin headers/sockets.
    [ThumbsUp.kicad_pcb, ThumbsUp.kicad_sch]
2026-06-11 v12: Minor corrections.
    [ThumbsUp.kicad_pcb, ThumbsUp.kicad_sch]
2026-06-11 v12: Cleaned up orphaned tracks, prepared for Gerbers generation..
    [ThumbsUp-B_Cu.gbr, ThumbsUp-B_Mask.gbr, ThumbsUp-B_Paste.gbr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]
2026-06-11 v12: Prepared Gerbers as ordered 2026-06-11.
    [ThumbsUp-B_Cu.gbr, ThumbsUp-B_Mask.gbr, ThumbsUp-B_Paste.gbr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]
2026-07-21 v12: Added/modified the tenting heels.
    [Bottom Plate rev.3.step, Bottom Plate rev.5.step, v12 rev5 Heel Left.stl]
